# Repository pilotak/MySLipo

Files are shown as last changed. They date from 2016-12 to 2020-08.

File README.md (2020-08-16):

# MySensors Li-po/USB powered wirelles node



PCB size as 18500 Li-po battery board with ATmega328p with integrated USB charger and battery protection IC. Supports ATSHA204A CryptoAuth chip, DS18B20 temperature IC and Meder reed switch.

### Power consumption
* sleep: 58.1uA
* wakeup: 18.2mA

### Supported radios:
* NRF24L01 SMD
* NRF24L01+LNA+PA SMD

### Pins used:
* D2 = reed switch 1
* D3 = reed switch 2
* D4 = 1-Wire bus with R2 pull-up to D5
* D5 = 1-Wire supply
* D7 = LED indication
* D9 = CE pin
* D10 = CSN
* SPI = radios
* A2 = ATSHA204A
* A7 = battery monitor

## PCB top view
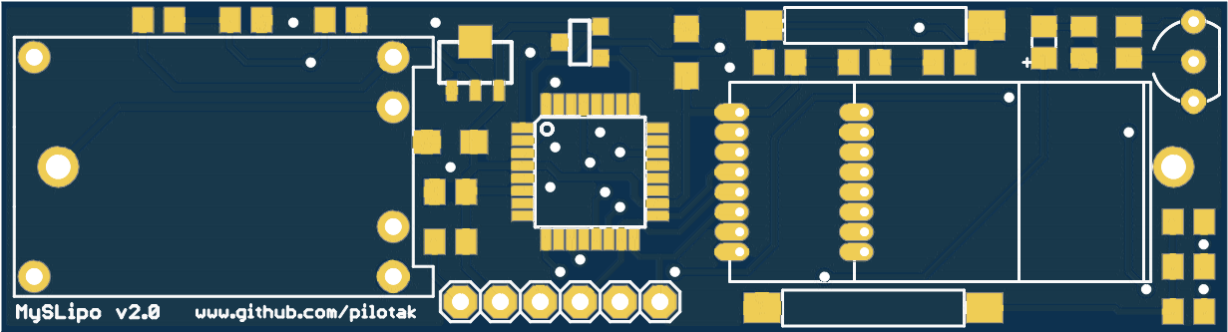
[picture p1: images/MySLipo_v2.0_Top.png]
PCB top view

## PCB bottom view
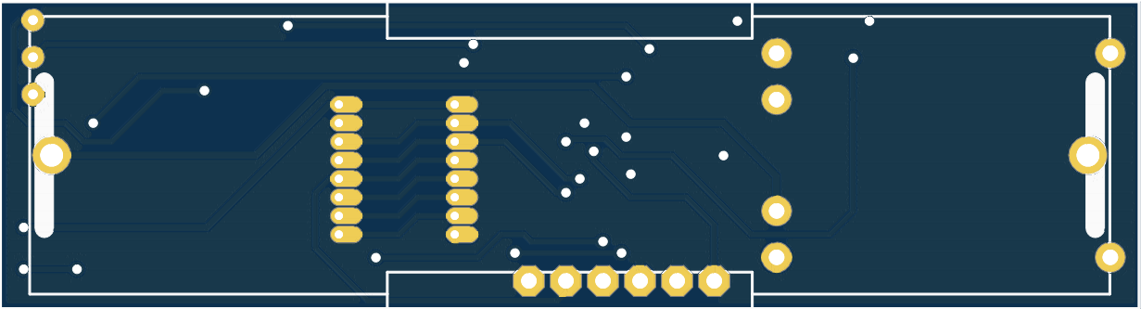
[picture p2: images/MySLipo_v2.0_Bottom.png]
PCB bottom view


### ATmega328p fuses
- **HIGH:** DA
- **LOW:** E2
- **EXTENDED:** 06

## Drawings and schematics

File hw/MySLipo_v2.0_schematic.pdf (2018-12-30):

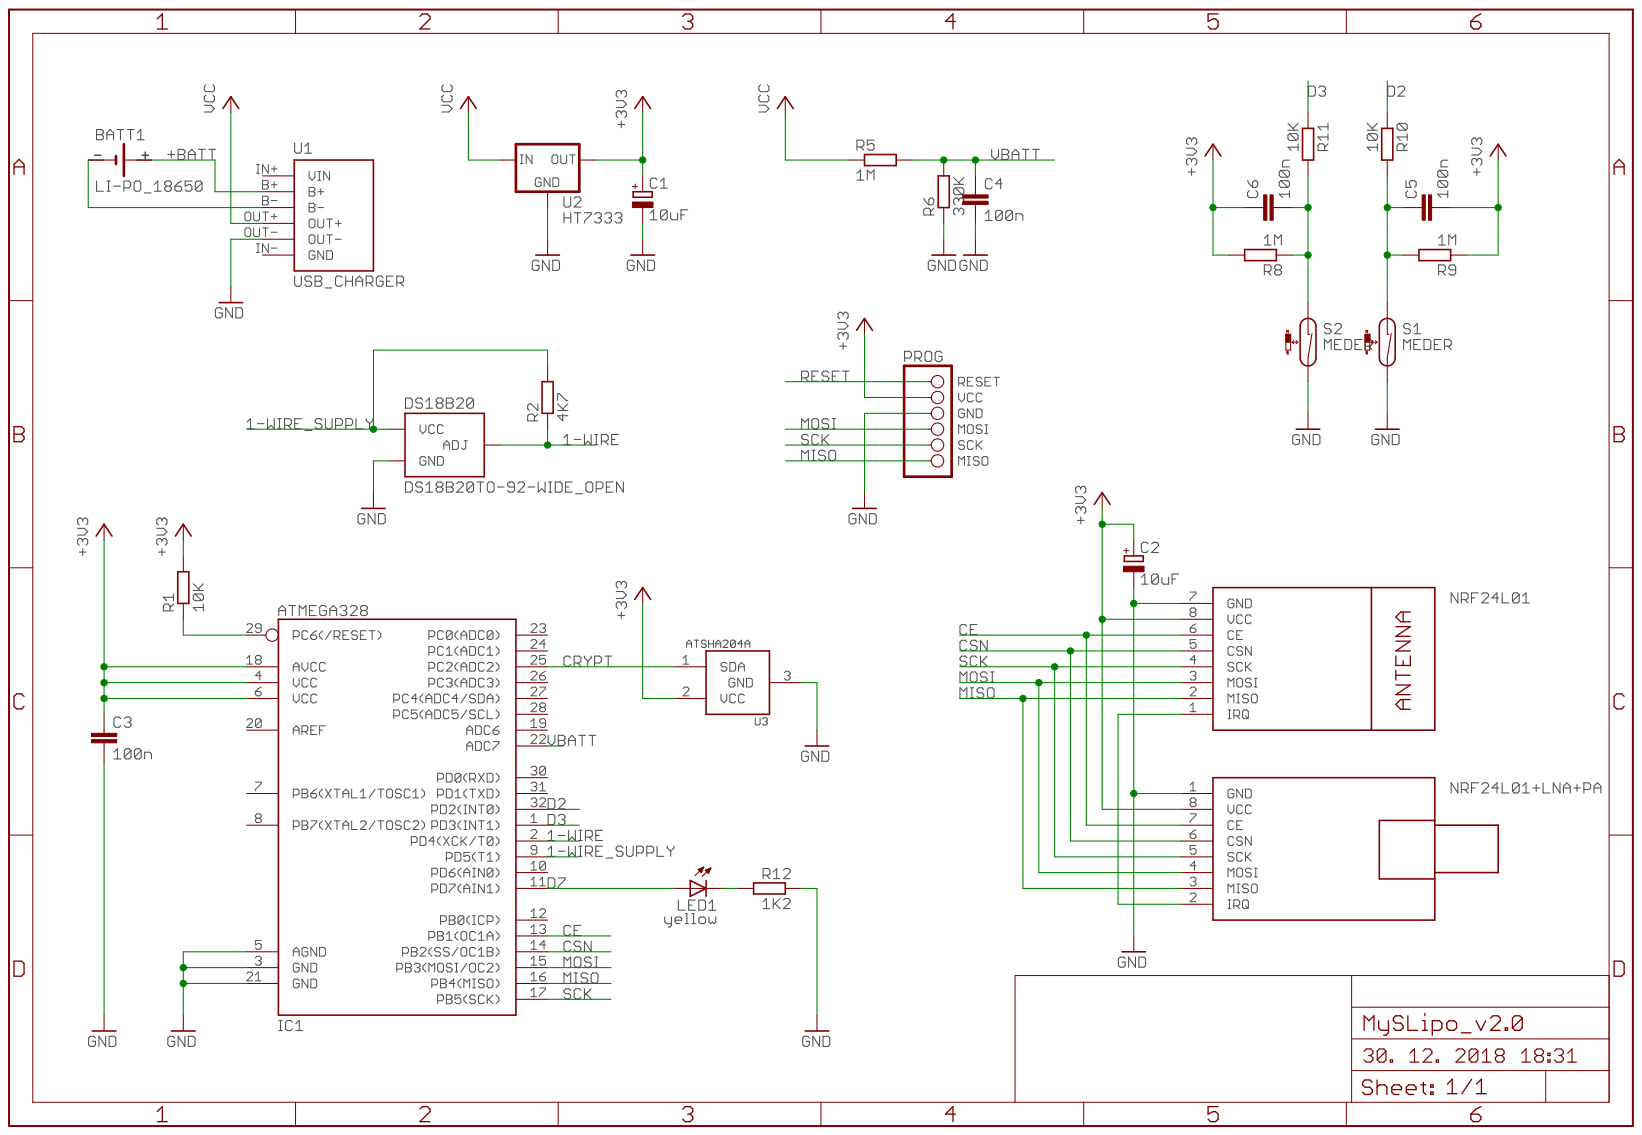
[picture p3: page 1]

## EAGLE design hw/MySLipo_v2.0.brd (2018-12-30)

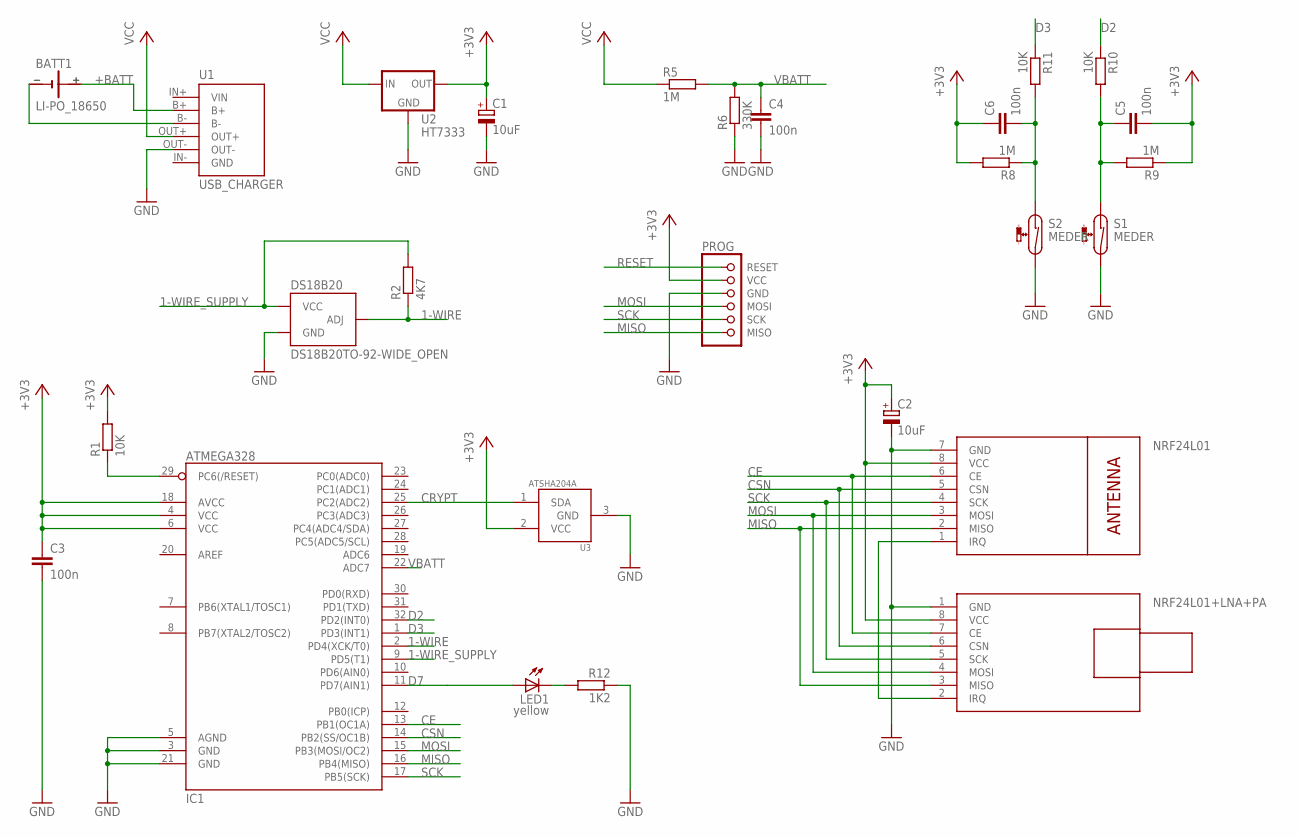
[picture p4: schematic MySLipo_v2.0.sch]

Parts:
BATT1: LI-PO_18650; 18650_HOLDER
C1, C2: 10uF; SMC_A
C3, C4, C5, C6: 100n; C0805
DS18B20: DS18B20TO-92-WIDE_OPEN; TO-92-WIDE_OPEN
IC1: ATMEGA328; TQFP32-08
LED1: yellow; LED_0805
NRF24L01: WIRELESS-NRF24L01SMD2; WIRELESS-NRF24L01-SMD-2
NRF24L01+LNA+PA: WIRELESS-NRF24L01-PA-EXTSMD; WIRELESS-NRF24L01-PA-SMD
PROG: PROG
R1, R10, R11: 10K; R0805
R2: 4K7; R0805
R5, R8, R9: 1M; R0805
R6: 330K; R0805
R12: 1K2; R0805
S1, S2: MEDER; 15X
U1: USB_CHARGER
U2: HT7333; SOT89
U3: ATSHA204A; SOT23-3

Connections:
1-WIRE: DS18B20.G (ADJ), IC1.2 (PD4(XCK/T0)), R2.1
1-WIRE_SUPPLY: DS18B20.S (VCC), IC1.9 (PD5(T1)), R2.2
+3V3: C1.+, C2.+, C3.1, C5.2, C6.1, IC1.4 (VCC), IC1.6 (VCC), IC1.18 (AVCC), NRF24L01.8 (VCC), NRF24L01+LNA+PA.8 (VCC), PROG.2 (VCC), R1.2, R8.2, R9.1, U2.3 (OUT), U3.2 (VCC)
+BATT: BATT1.+, U1.B+
CE: IC1.13 (PB1(OC1A)), NRF24L01.6 (CE), NRF24L01+LNA+PA.7 (CE)
CRYPT: IC1.25 (PC2(ADC2)), U3.1 (SDA)
CSN: IC1.14 (PB2(SS/OC1B)), NRF24L01.5 (CSN), NRF24L01+LNA+PA.6 (CSN)
D2: IC1.32 (PD2(INT0)), R10.1
D3: IC1.1 (PD3(INT1)), R11.1
D7: IC1.11 (PD7(AIN1)), LED1.1 (A)
GND: C1.-, C2.-, C3.2, C4.2, DS18B20.D (GND), IC1.3 (GND), IC1.5 (AGND), IC1.21 (GND), NRF24L01.7 (GND), NRF24L01+LNA+PA.1 (GND), PROG.3 (GND), R6.1, R12.1, S1.P$2 (2), S2.P$2 (2), U1.OUT-, U2.1 (GND), U3.3 (GND)
MISO: IC1.16 (PB4(MISO)), NRF24L01.2 (MISO), NRF24L01+LNA+PA.3 (MISO), PROG.6 (MISO)
MOSI: IC1.15 (PB3(MOSI/OC2)), NRF24L01.3 (MOSI), NRF24L01+LNA+PA.4 (MOSI), PROG.4 (MOSI)
unnamed: NRF24L01.1 (IRQ), NRF24L01+LNA+PA.2 (IRQ)
unnamed: C5.1, R9.2, R10.2, S1.P$1 (1)
unnamed: C6.2, R8.1, R11.2, S2.P$1 (1)
unnamed: BATT1.-, U1.B-
unnamed: LED1.2 (C), R12.2
RESET: IC1.29 (PC6(/RESET)), PROG.1 (RESET), R1.1
SCK: IC1.17 (PB5(SCK)), NRF24L01.4 (SCK), NRF24L01+LNA+PA.5 (SCK), PROG.5 (SCK)
VBATT: C4.1, IC1.22 (ADC7), R5.2, R6.2
VCC: R5.1, U1.OUT+, U2.2 (IN)

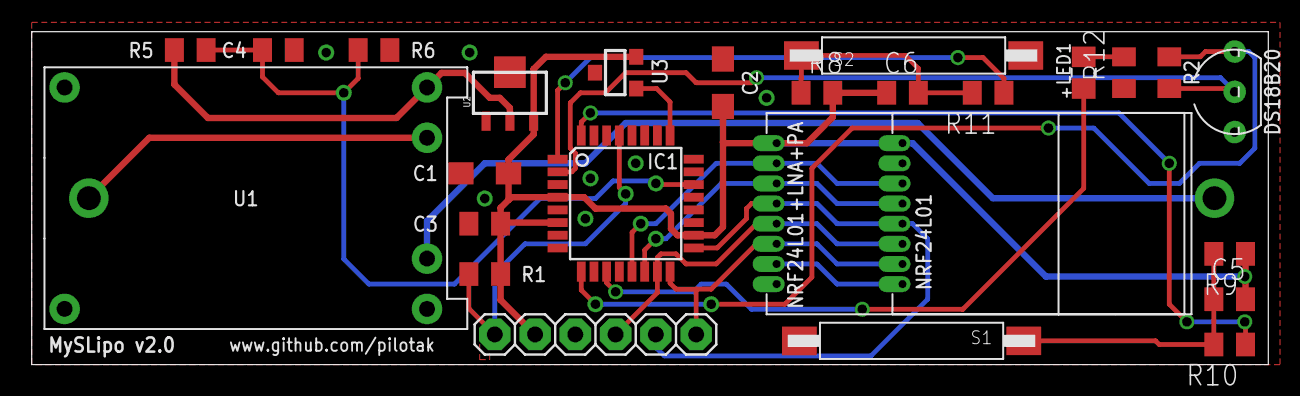
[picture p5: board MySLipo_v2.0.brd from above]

Board: 2 copper layers, 78.0 x 21.0 mm, 27 parts (1 on the bottom side), 22 nets.

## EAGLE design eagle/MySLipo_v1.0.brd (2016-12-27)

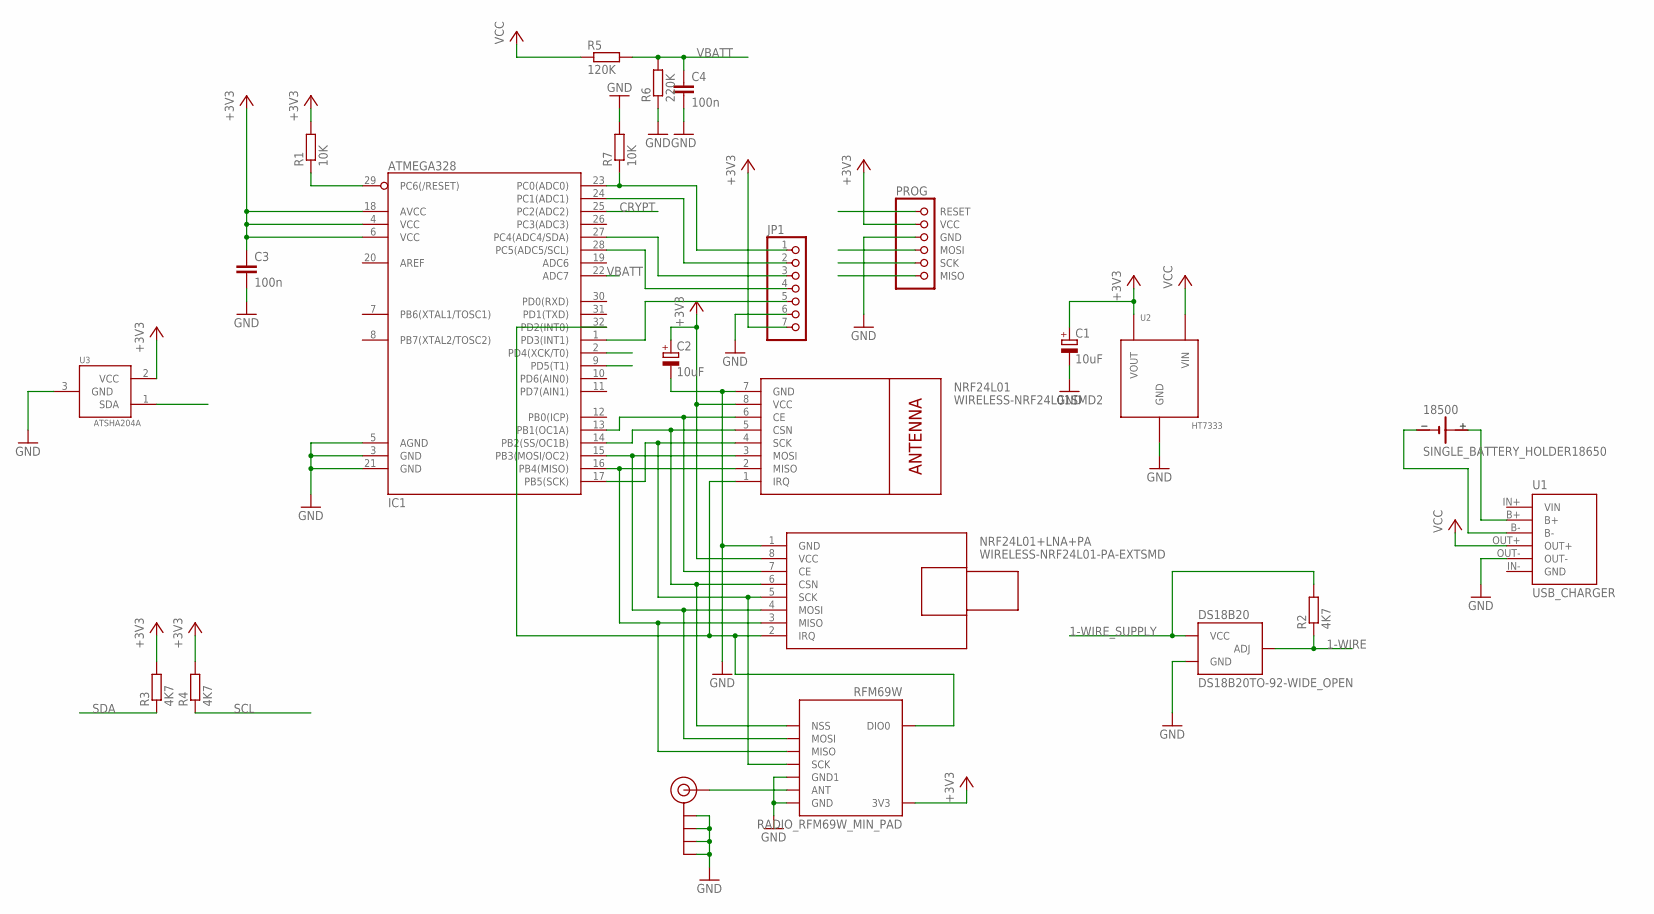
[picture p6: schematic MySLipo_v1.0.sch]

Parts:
18500: SINGLE_BATTERY_HOLDER18650; 18650_HOLDER
C1, C2: 10uF; SMC_A
C3, C4: 100n; C0805
DS18B20: DS18B20TO-92-WIDE_OPEN; TO-92-WIDE_OPEN
IC1: ATMEGA328; TQFP32-08
J$1: ANTENNATINY; SMA_UFL_PAD_TINY
JP1: PINHD-1X7; 1X07
NRF24L01: WIRELESS-NRF24L01SMD2; WIRELESS-NRF24L01-SMD-2
NRF24L01+LNA+PA: WIRELESS-NRF24L01-PA-EXTSMD; WIRELESS-NRF24L01-PA-SMD
PROG: PROG
R1, R7: 10K; R0805
R2, R3, R4: 4K7; R0805
R5: 120K; R0805
R6: 220K; R0805
RFM69W: RADIO_RFM69W_MIN_PAD; RFM69W_MIN_PAD
U1: USB_CHARGER
U2: HT7333; SOT-89
U3: ATSHA204A; SOT23-3

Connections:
1-WIRE: DS18B20.G (ADJ), IC1.2 (PD4(XCK/T0)), R2.1
1-WIRE_SUPPLY: DS18B20.D (VCC), IC1.9 (PD5(T1)), R2.2
+3V3: C1.+, C2.+, C3.1, IC1.4 (VCC), IC1.6 (VCC), IC1.18 (AVCC), JP1.7, NRF24L01.8 (VCC), NRF24L01+LNA+PA.8 (VCC), PROG.2 (VCC), R1.2, R3.2, R4.2, RFM69W.8 (3V3), U2.3 (VOUT), U3.2 (VCC)
A0: IC1.23 (PC0(ADC0)), JP1.1, R7.1
A1: IC1.24 (PC1(ADC1)), JP1.2
ANT: J$1.ANT1 (SIGNAL), J$1.ANT2 (SIGNAL), J$1.ANT3 (SIGNAL), RFM69W.10 (ANT)
CRYPT: IC1.25 (PC2(ADC2)), U3.1 (SDA)
D2: IC1.1 (PD3(INT1)), JP1.5
GND: C1.-, C2.-, C3.2, C4.2, DS18B20.S (GND), IC1.3 (GND), IC1.5 (AGND), IC1.21 (GND), J$1.GND1 (GND), J$1.GND2 (GND), J$1.GND3 (GND), J$1.GND4 (GND), JP1.6, NRF24L01.7 (GND), NRF24L01+LNA+PA.1 (GND), PROG.3 (GND), R6.1, R7.2, RFM69W.9 (GND), RFM69W.11 (GND1), U1.OUT-, U2.1 (GND), U3.3 (GND)
MISO: IC1.16 (PB4(MISO)), NRF24L01.2 (MISO), NRF24L01+LNA+PA.3 (MISO), PROG.6 (MISO), RFM69W.13 (MISO)
MOSI: IC1.15 (PB3(MOSI/OC2)), NRF24L01.3 (MOSI), NRF24L01+LNA+PA.4 (MOSI), PROG.4 (MOSI), RFM69W.14 (MOSI)
unnamed: IC1.32 (PD2(INT0)), NRF24L01.1 (IRQ), NRF24L01+LNA+PA.2 (IRQ), RFM69W.2 (DIO0)
unnamed: IC1.13 (PB1(OC1A)), NRF24L01.6 (CE), NRF24L01+LNA+PA.7 (CE)
unnamed: IC1.14 (PB2(SS/OC1B)), NRF24L01.5 (CSN), NRF24L01+LNA+PA.6 (CSN), RFM69W.15 (NSS)
unnamed: 18500.+, U1.B+
unnamed: 18500.-, U1.B-
RESET: IC1.29 (PC6(/RESET)), PROG.1 (RESET), R1.1
SCK: IC1.17 (PB5(SCK)), NRF24L01.4 (SCK), NRF24L01+LNA+PA.5 (SCK), PROG.5 (SCK), RFM69W.12 (SCK)
SCL: IC1.28 (PC5(ADC5/SCL)), JP1.4, R4.1
SDA: IC1.27 (PC4(ADC4/SDA)), JP1.3, R3.1
VBATT: C4.1, IC1.22 (ADC7), R5.2, R6.2
VCC: R5.1, U1.OUT+, U2.2 (VIN), U2.2@1 (VIN)

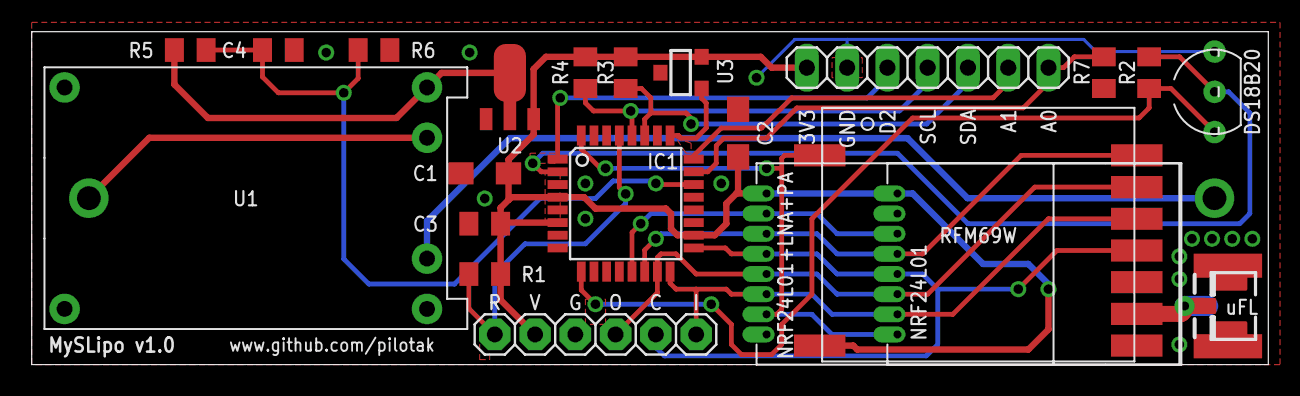
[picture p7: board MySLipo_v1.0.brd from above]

Board: 2 copper layers, 78.0 x 21.0 mm, 23 parts (1 on the bottom side), 22 nets.

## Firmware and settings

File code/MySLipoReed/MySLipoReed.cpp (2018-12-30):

/*
MIT License
Copyright (c) 2018 Pavel Slama
Permission is hereby granted, free of charge, to any person obtaining a copy
of this software and associated documentation files (the "Software"), to deal
in the Software without restriction, including without limitation the rights
to use, copy, modify, merge, publish, distribute, sublicense, and/or sell
copies of the Software, and to permit persons to whom the Software is
furnished to do so, subject to the following conditions:
The above copyright notice and this permission notice shall be included in all
copies or substantial portions of the Software.
THE SOFTWARE IS PROVIDED "AS IS", WITHOUT WARRANTY OF ANY KIND, EXPRESS OR
IMPLIED, INCLUDING BUT NOT LIMITED TO THE WARRANTIES OF MERCHANTABILITY,
FITNESS FOR A PARTICULAR PURPOSE AND NONINFRINGEMENT. IN NO EVENT SHALL THE
AUTHORS OR COPYRIGHT HOLDERS BE LIABLE FOR ANY CLAIM, DAMAGES OR OTHER
LIABILITY, WHETHER IN AN ACTION OF CONTRACT, TORT OR OTHERWISE, ARISING FROM,
OUT OF OR IN CONNECTION WITH THE SOFTWARE OR THE USE OR OTHER DEALINGS IN THE
SOFTWARE.
*/

#include <Arduino.h>
#include <MySensors.h>

const int battery_pin = A7;
const int reed1_pin = 2;
const int reed2_pin = 3;
const int led_pin = 7;

#define REED1_CHILD_ID 1
#define REED2_CHILD_ID 2

bool prev_value[2]  = {false, false};

MyMessage msg(REED1_CHILD_ID, V_TRIPPED);
MyMessage msg2(REED2_CHILD_ID, V_TRIPPED);

void presentation() {
    sendSketchInfo("MySLipoReed", SKETCH_VER);
    present(REED1_CHILD_ID, S_DOOR);
    // sleep(5);
    present(REED2_CHILD_ID, S_DOOR);
}

void setup() {
    analogReference(INTERNAL);
    pinMode(reed1_pin, INPUT);
    pinMode(reed2_pin, INPUT);
}

void loop() {
    bool value;

    pinMode(led_pin, OUTPUT);
    wait(1);
    digitalWrite(led_pin, HIGH);

    value = digitalRead(reed1_pin);

    if (value != prev_value[0]) {
#ifdef MY_DEBUG
        Serial.println("Reed switch 1 changed\n");
#endif

        send(msg.set(value == HIGH));
        prev_value[0] = value;
    }

    value = digitalRead(reed2_pin);

    if (value != prev_value[1]) {
#ifdef MY_DEBUG
        Serial.println("Reed switch 2 changed\n");
#endif

        send(msg2.set(value == HIGH));
        prev_value[1] = value;
    }

    // get the battery Voltage
    uint32_t battery_v = analogRead(battery_pin) * 1000000;
    battery_v /= 2363076;  // (0,1*1024/4,3333333)*100000; adc to voltage conversion
    uint8_t battery_p = map(battery_v, 300, 420, 0, 100);  // voltage to percentage
    battery_p = constrain(battery_p, 0, 100);  // prevet overflow

#ifdef MY_DEBUG
    Serial.print("Battery voltage: ");
    Serial.print(battery_v);
    Serial.println(" V(*100)");
    Serial.print("Battery percentage: ");
    Serial.print(battery_p);
    Serial.println(" %");
#endif

    sendBatteryLevel(battery_p);

    digitalWrite(led_pin, LOW);
    pinMode(led_pin, INPUT);

    // Sleep until something happens with the sensor
    sleep(digitalPinToInterrupt(reed1_pin), CHANGE, digitalPinToInterrupt(reed2_pin), CHANGE, 0);
}

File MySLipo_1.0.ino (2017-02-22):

/**
 * The MySensors Arduino library handles the wireless radio link and protocol
 * between your home built sensors/actuators and HA controller of choice.
 * The sensors forms a self healing radio network with optional repeaters. Each
 * repeater and gateway builds a routing tables in EEPROM which keeps track of the
 * network topology allowing messages to be routed to nodes.
 *
 * Created by Henrik Ekblad <henrik.ekblad@mysensors.org>
 * Copyright (C) 2013-2015 Sensnology AB
 * Full contributor list: https://github.com/mysensors/Arduino/graphs/contributors
 *
 * Documentation: http://www.mysensors.org
 * Support Forum: http://forum.mysensors.org
 *
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
 *******************************
 *
 * DESCRIPTION
 *
 * This is an example that demonstrates how to report the battery level for a sensor
 * Instructions for measuring battery capacity on A0 are available here:
 * http://www.mysensors.org/build/battery
 *
 */

//#define MY_DEBUG

#define MY_OTA_FIRMWARE_FEATURE
#define MY_RADIO_NRF24
#define MY_RF24_PA_LEVEL RF24_PA_MAX // RF24_PA_MAX

#include <MySensors.h>
#include <DallasTemperature.h>
#include <OneWire.h>

const int BATTERY_SENSE_PIN = A7;
const int ONE_WIRE_PIN = 4;
const int ONE_WIRE_SUPPLY_PIN = 5;
const unsigned long SLEEP_TIME = 600000;  // sleep time between reads (seconds * 1000 milliseconds)

const byte temp_resolution = 12; // 12bit 
const unsigned int temp_wait = (750 / (1 << (12 - temp_resolution)))+30;

#define CHILD_ID 0

OneWire oneWire(ONE_WIRE_PIN); // Setup a oneWire instance to communicate with any OneWire devices (not just Maxim/Dallas temperature ICs)
DallasTemperature sensors(&oneWire);
MyMessage msg(CHILD_ID, V_TEMP);

void before(){
  // Startup up the OneWire library
  sensors.begin();
  sensors.setResolution(temp_resolution);
}

void setup(){
  analogReference(INTERNAL);
  sensors.setWaitForConversion(false);
}

void presentation(){
  // Send the sketch version information to the gateway and Controller
  sendSketchInfo("MySLipo", "1.0");
  present(CHILD_ID, S_TEMP);
}

void loop(){
  // supply voltage to Dallas
  pinMode(ONE_WIRE_SUPPLY_PIN, OUTPUT);
  wait(1);
  digitalWrite(ONE_WIRE_SUPPLY_PIN, HIGH);

  sensors.requestTemperatures();
  sleep(temp_wait);
  
  float temperature = sensors.getTempCByIndex(0);
  digitalWrite(ONE_WIRE_SUPPLY_PIN, LOW); // turn off supply for Dallas
  
#ifdef MY_DEBUG
  Serial.print("Temp: ");
  Serial.print(temperature);
  Serial.println(" C");
#endif
  
  if(temperature != -127.00 && temperature < 85.00) { // if valid reading, send
    send(msg.set(temperature,2));
  }
  
  // get the battery Voltage
  float batteryV = analogRead(BATTERY_SENSE_PIN) * 0.00433365917; //((R1+R2)/R2)*1.1/1023
  byte batteryP = mapfloat(batteryV, 2.5, 4.2, 0, 100); // 2.5V cutoff voltage for USB charger circut, 4.2V fully charged Li-po
  batteryP = constrain(batteryP, 0, 100); // prevet overflow

#ifdef MY_DEBUG
  Serial.print("Battery voltage: ");
  Serial.print(batteryV);
  Serial.println(" V");
  Serial.print("Battery percentage: ");
  Serial.print(batteryP);
  Serial.println(" %");
#endif

  sendBatteryLevel(batteryP);

  pinMode(ONE_WIRE_SUPPLY_PIN, INPUT);
  sleep(SLEEP_TIME - 1 - temp_wait); // 1 millis after PinMode, temp_wait conversion of dallas
}

float mapfloat(float x, float in_min, float in_max, float out_min, float out_max){
 return (x - in_min) * (out_max - out_min) / (in_max - in_min) + out_min;
}

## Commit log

2016-12-27 src files
    [MySLipo_v1.0.brd, MySLipo_v1.0.sch]
2017-02-24 power consumption info
2017-09-11 LED added to FW
2018-12-30 eagle update
    [MySLipo_v2.0.brd, MySLipo_v2.0.sch]
2020-08-16 folder restructure
    [MySLipo_v2.0.brd, MySLipo_v2.0.sch]

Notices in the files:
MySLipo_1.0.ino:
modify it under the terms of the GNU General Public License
